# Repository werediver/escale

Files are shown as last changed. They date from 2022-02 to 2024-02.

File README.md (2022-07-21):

# Kitchen / coffee scale

This is a kitchen / coffee scale project repository. Contains both the hardware design files and the firmware source code.

## Prototype one

- [Raspberry Pi Pico](https://www.raspberrypi.com/products/raspberry-pi-pico/)
- Firmware in Rust ([escale_fw_rs](escale_fw_rs/))
- Battery powered (AA×2)

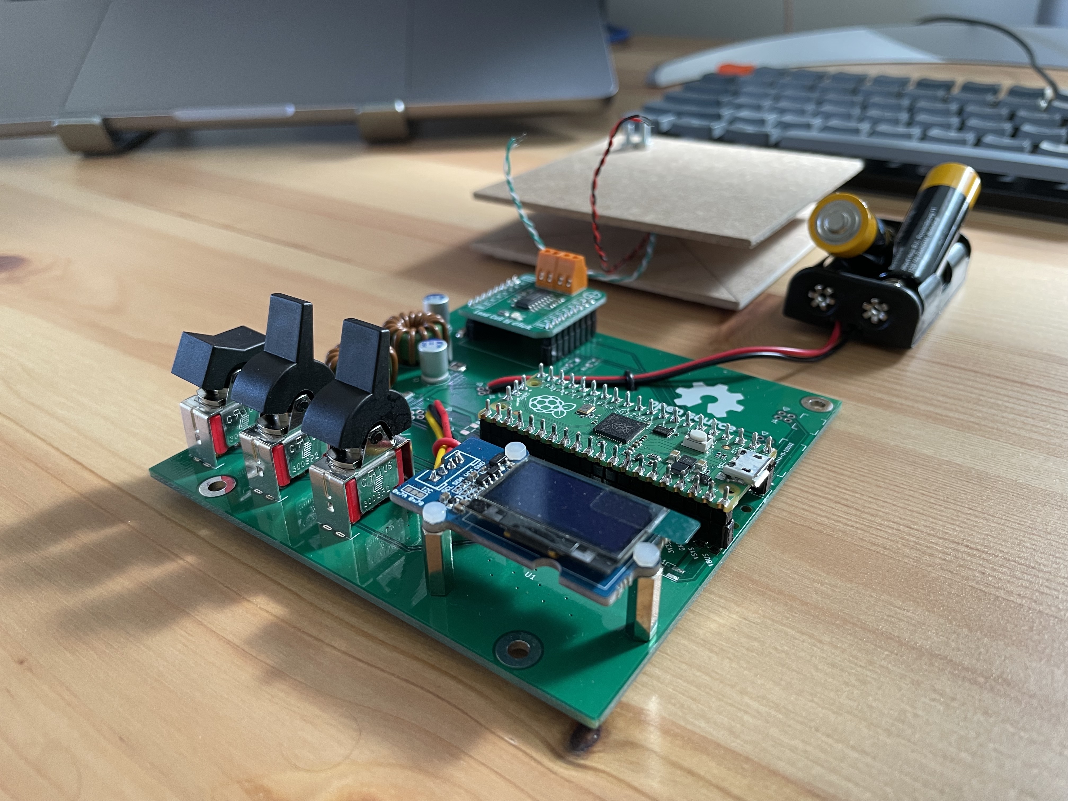
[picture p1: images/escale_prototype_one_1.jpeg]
eScale prototype one


## Prototype zero

The firmware source code is at a very early stage of development. See [escale_fw](escale_fw).

The hardware prototype is assembled on a breadboard and consists of the following components:

- [Seeeduino XIAO](https://wiki.seeedstudio.com/Seeeduino-XIAO/)
- [0.96" SSD1315 OLED display](https://wiki.seeedstudio.com/Grove-OLED-Display-0.96-SSD1315/)
- [MikroE Load Cell 2 Click](https://www.mikroe.com/load-cell-2-click)
- Two 12 mm THT-mount push-buttons

eScale prototype zero with a table

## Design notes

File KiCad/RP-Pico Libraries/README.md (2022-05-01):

# Raspberry Pi Pico KiCad symbols and footprints

Based on [ncarandini/KiCad-RP-Pico](https://github.com/ncarandini/KiCad-RP-Pico/).

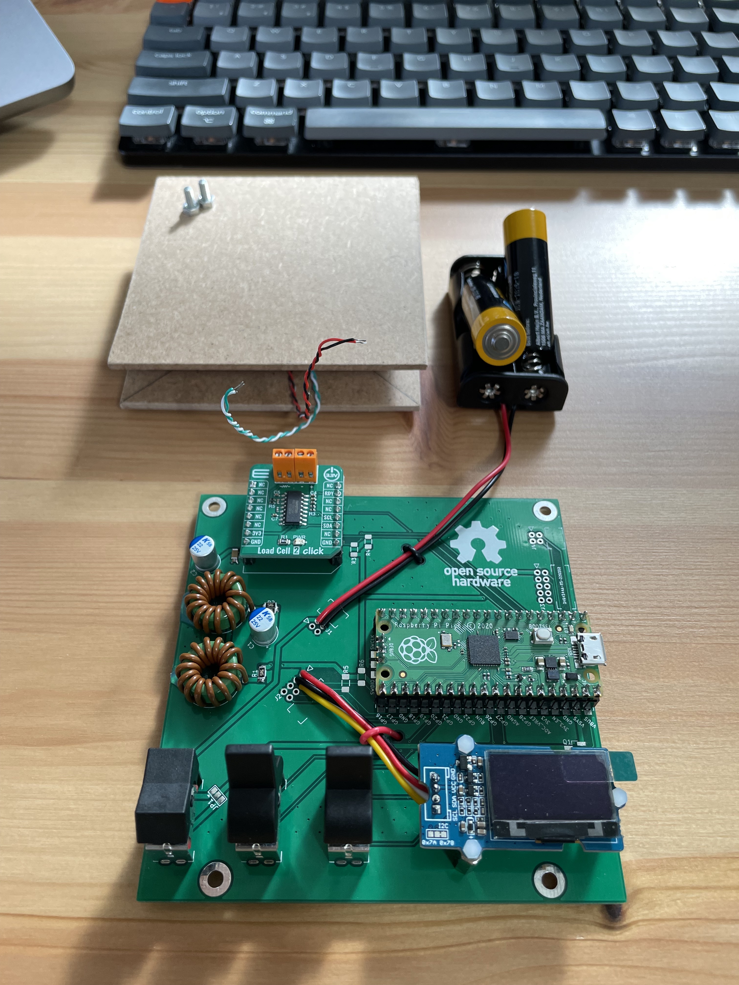
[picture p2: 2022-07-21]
images/escale_prototype_one_2.jpeg

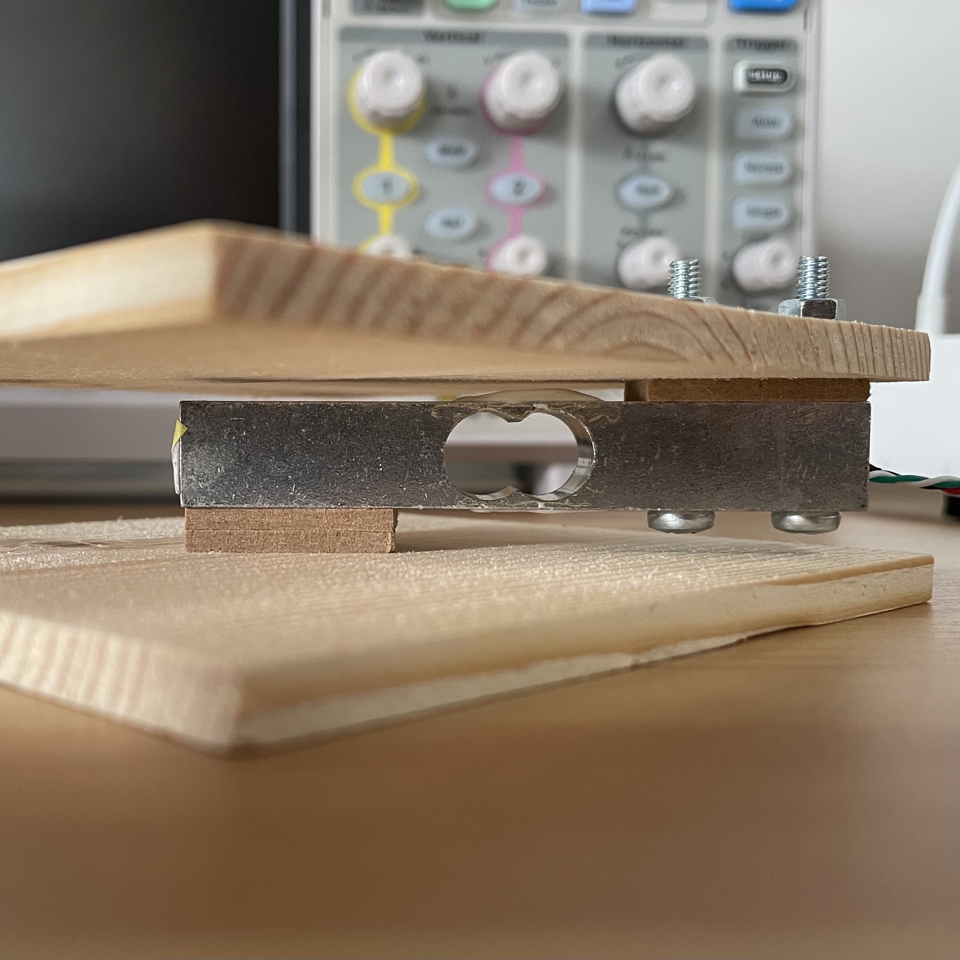
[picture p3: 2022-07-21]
images/escale_prototype_zero_table_close-up.jpg

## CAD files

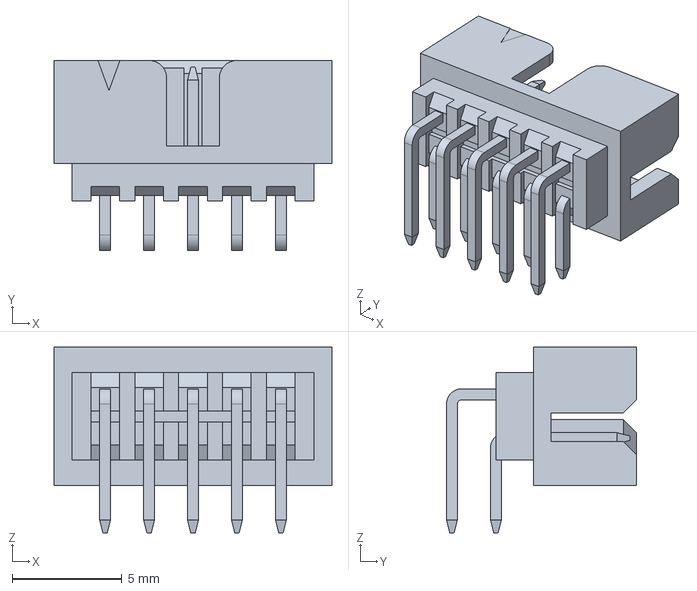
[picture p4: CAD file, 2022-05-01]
KiCad/Molex Milli-Grid/87833-1020.stp
12.7 x 8.65 x 8.46 mm

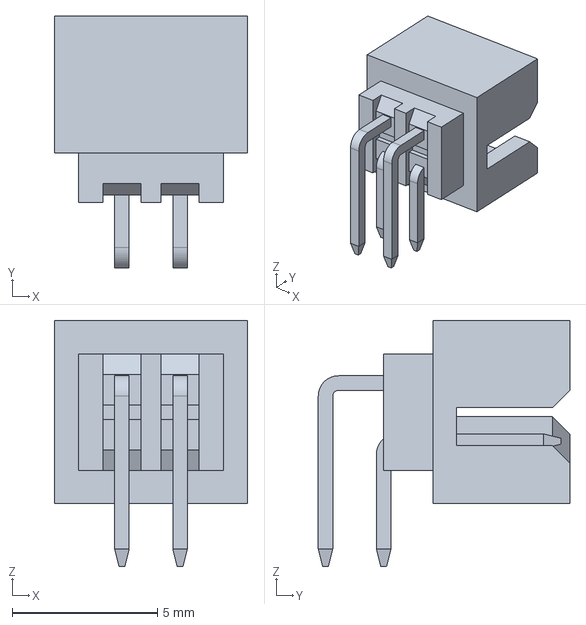
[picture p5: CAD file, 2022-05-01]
KiCad/Molex Milli-Grid/87833-0420.stp
6.65 x 8.65 x 8.46 mm

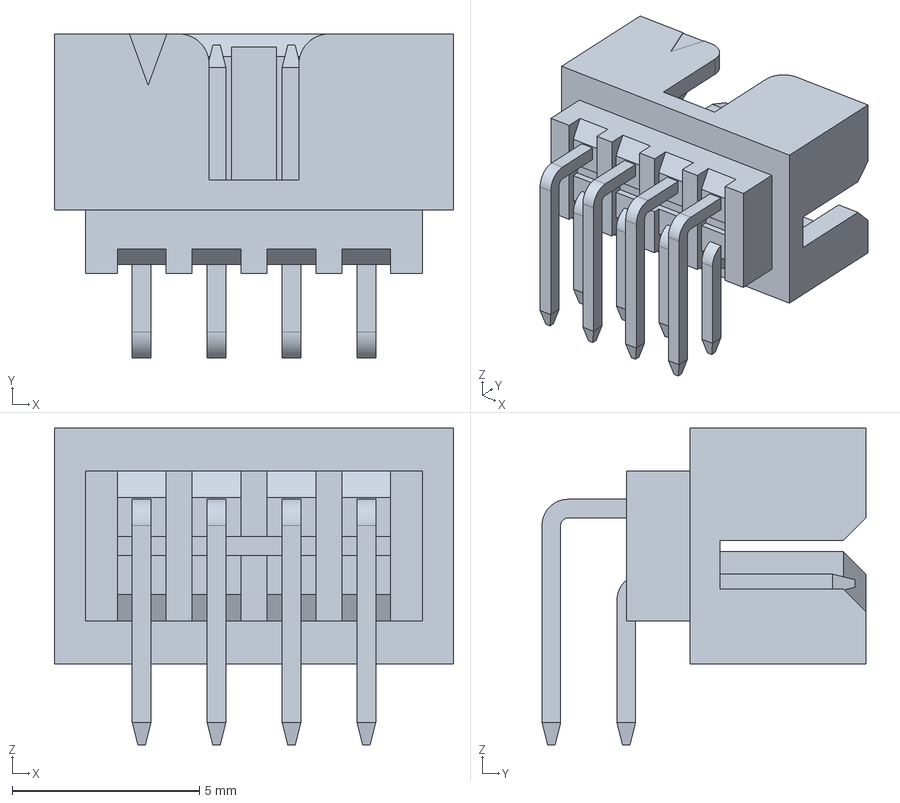
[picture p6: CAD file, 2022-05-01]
KiCad/Molex Milli-Grid/87833-0820.stp
10.7 x 8.65 x 8.46 mm

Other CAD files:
KiCad/Molex Milli-Grid/87833-0420.dxf
KiCad/Molex Milli-Grid/87833-0820.dxf
KiCad/Molex Milli-Grid/87833-1020.dxf

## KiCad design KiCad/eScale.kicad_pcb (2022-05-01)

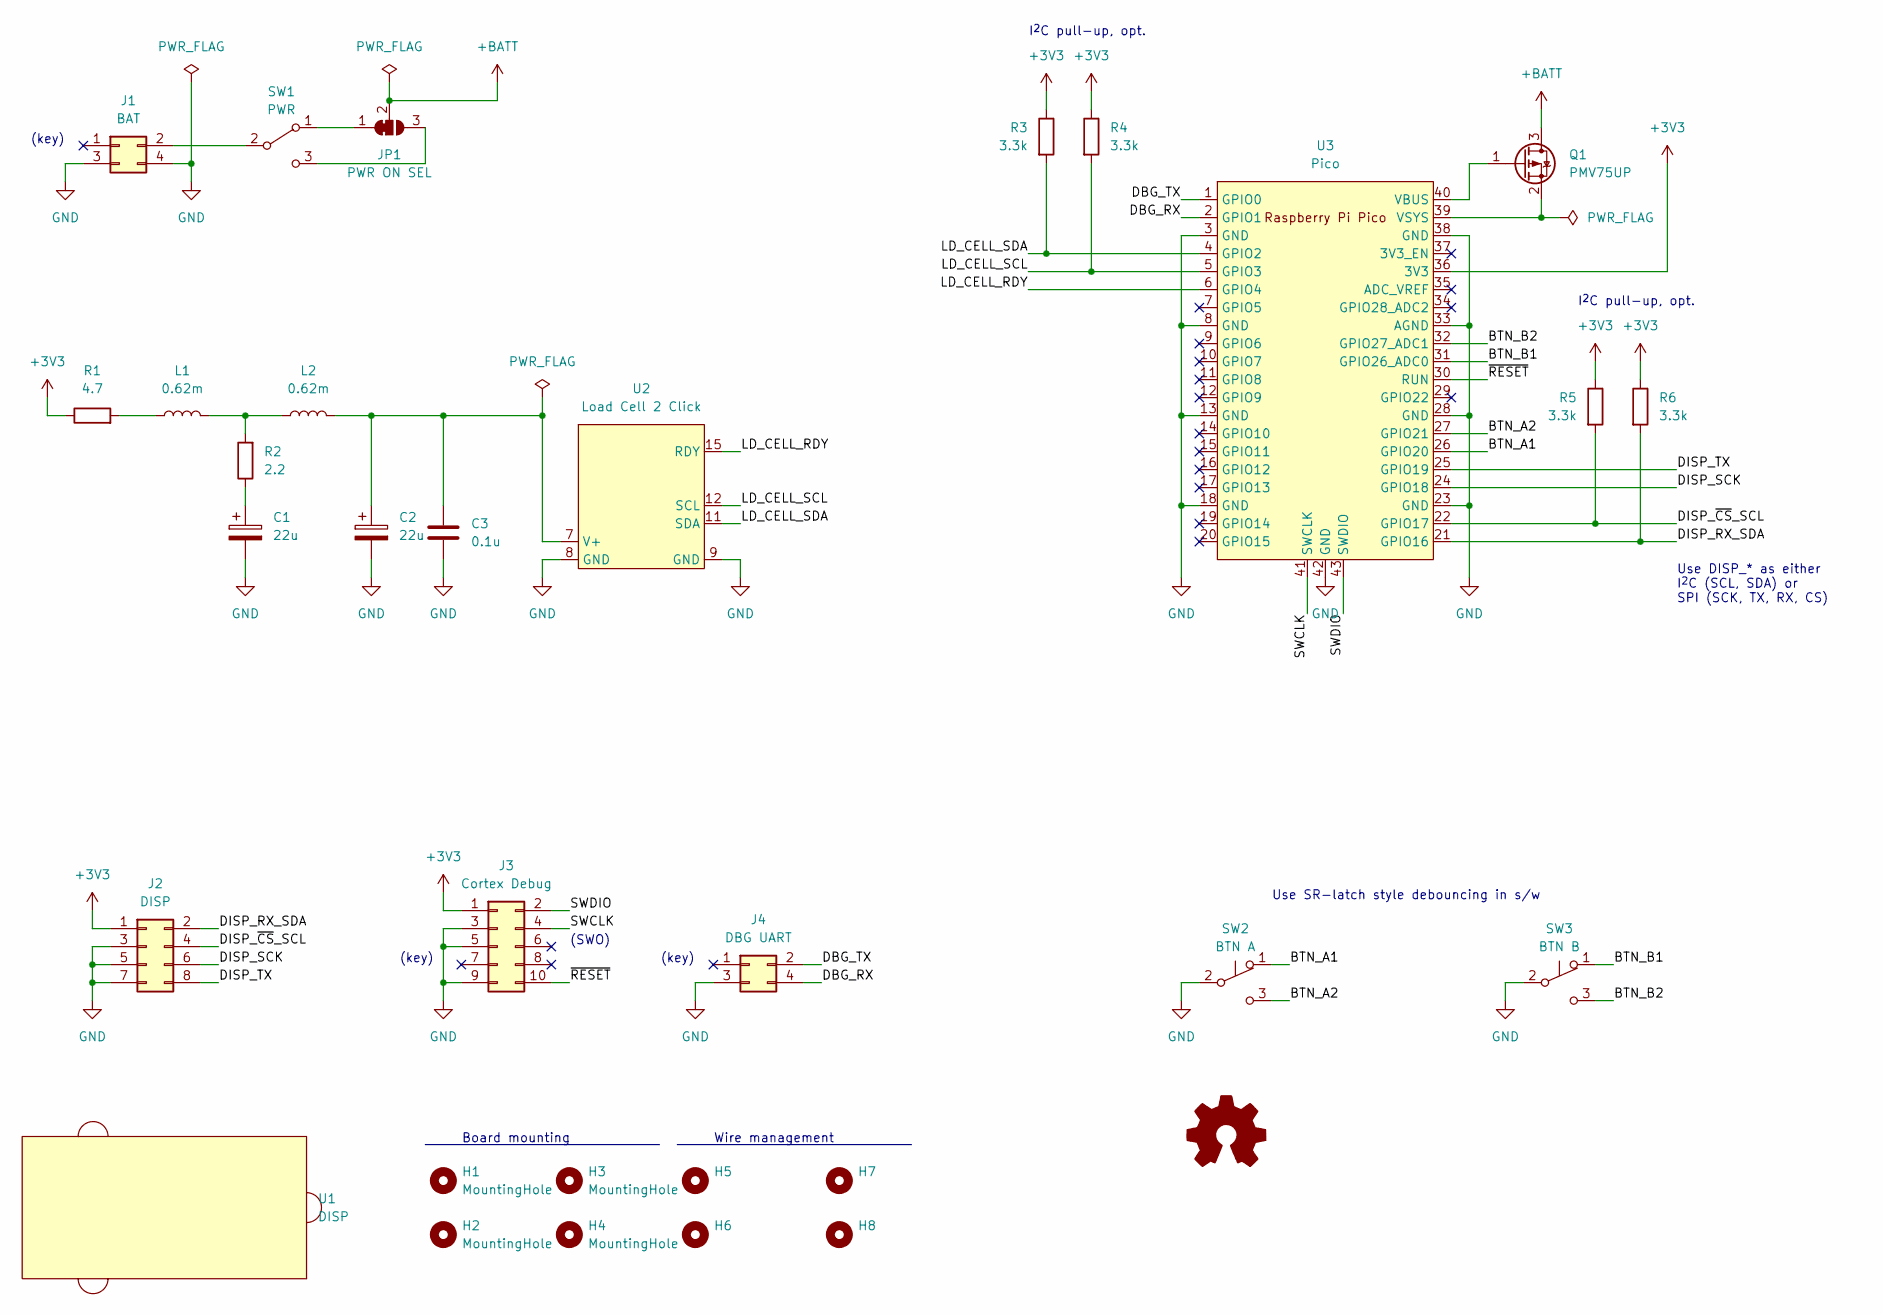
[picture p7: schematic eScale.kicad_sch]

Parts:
C1, C2: 22u; CP_Radial_D6.3mm_P2.50mm
C3: 0.1u; C_1206_3216Metric_Pad1.33x1.80mm_HandSolder
H1, H2, H3, H4: MountingHole; MountingHole_3.2mm_M3_Pad
H5, H6, H7, H8: (no value)
J1: BAT; Molex_Milli-Grid_87833-04xx
J2: DISP; Molex_Milli-Grid_87833-08xx
J3: Cortex Debug; Molex_Milli-Grid_87833-10xx
J4: DBG UART; Molex_Milli-Grid_87833-04xx
JP1: PWR ON SEL; SolderJumper-3_P1.3mm_Bridged12_Pad1.0x1.5mm
L1, L2: 0.62m; L_D13.3_d7.3_Horizontal
LOGO1: (no value)
Q1: PMV75UP; SOT-23_Handsoldering
R1: 4.7; R_1206_3216Metric_Pad1.30x1.75mm_HandSolder
R2: 2.2; R_1206_3216Metric_Pad1.30x1.75mm_HandSolder
R3, R4, R5, R6: 3.3k; R_1206_3216Metric_Pad1.30x1.75mm_HandSolder
SW1: PWR; 300SPxxxxxxVS2xx
SW2: BTN A; 300SPxxxxxxVS2xx
SW3: BTN B; 300SPxxxxxxVS2xx
U1: DISP; Seeed_Grove_20x40
U2: Load Cell 2 Click; MikroE Click
U3: Pico; RPi_Pico_SMD_TH

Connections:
+3V3: J2.1, J3.1, R1.1, R3.1, R4.1, R5.1, R6.1, U3.36 (3V3)
+BATT: JP1.2 (C), Q1.3 (D)
/BTN_A1: SW2.1 (A), U3.26 (GPIO20)
/BTN_A2: SW2.3 (C), U3.27 (GPIO21)
/BTN_B1: SW3.1 (A), U3.31 (GPIO26_ADC0)
/BTN_B2: SW3.3 (C), U3.32 (GPIO27_ADC1)
/DBG_RX: J4.4, U3.2 (GPIO1)
/DBG_TX: J4.2, U3.1 (GPIO0)
/DISP_RX_SDA: J2.2, R6.2, U3.21 (GPIO16)
/DISP_SCK: J2.6, U3.24 (GPIO18)
/DISP_TX: J2.8, U3.25 (GPIO19)
/DISP_~CS_SCL: J2.4, R5.2, U3.22 (GPIO17)
/LD_CELL_RDY: U2.15 (RDY), U3.6 (GPIO4)
/LD_CELL_SCL: R4.2, U2.12 (SCL), U3.5 (GPIO3)
/LD_CELL_SDA: R3.2, U2.11 (SDA), U3.4 (GPIO2)
/SWCLK: J3.4, U3.41 (SWCLK)
/SWDIO: J3.2, U3.43 (SWDIO)
/~RESET: J3.10, U3.30 (RUN)
GND: C1.2, C2.2, C3.2, J1.3, J1.4, J2.3, J2.5, J2.7, J3.3, J3.5, J3.9, J4.3, SW2.2 (B), SW3.2 (B), U2.8 (GND), U2.9 (GND), U3.3 (GND), U3.8 (GND), U3.13 (GND), U3.18 (GND), U3.23 (GND), U3.28 (GND), U3.33 (AGND), U3.38 (GND), U3.42 (GND)
unnamed: C1.1, R2.1
unnamed: C2.1, C3.1, L2.2, U2.7 (V+)
unnamed: J1.2, SW1.2 (B)
unnamed: JP1.1 (A), SW1.1 (A)
unnamed: JP1.3 (B), SW1.3 (C)
unnamed: L1.1, R1.2
unnamed: L1.2, L2.1, R2.2
unnamed: Q1.1 (G), U3.40 (VBUS)
unnamed: Q1.2 (S), U3.39 (VSYS)

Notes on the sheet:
(key)
Board mounting
Use SR-latch style debouncing in s/w
I^{2}C pull-up, opt.
Use DISP_* as either I^{2}C (SCL, SDA) or SPI (SCK, TX, RX, CS)
(SWO)
Wire management

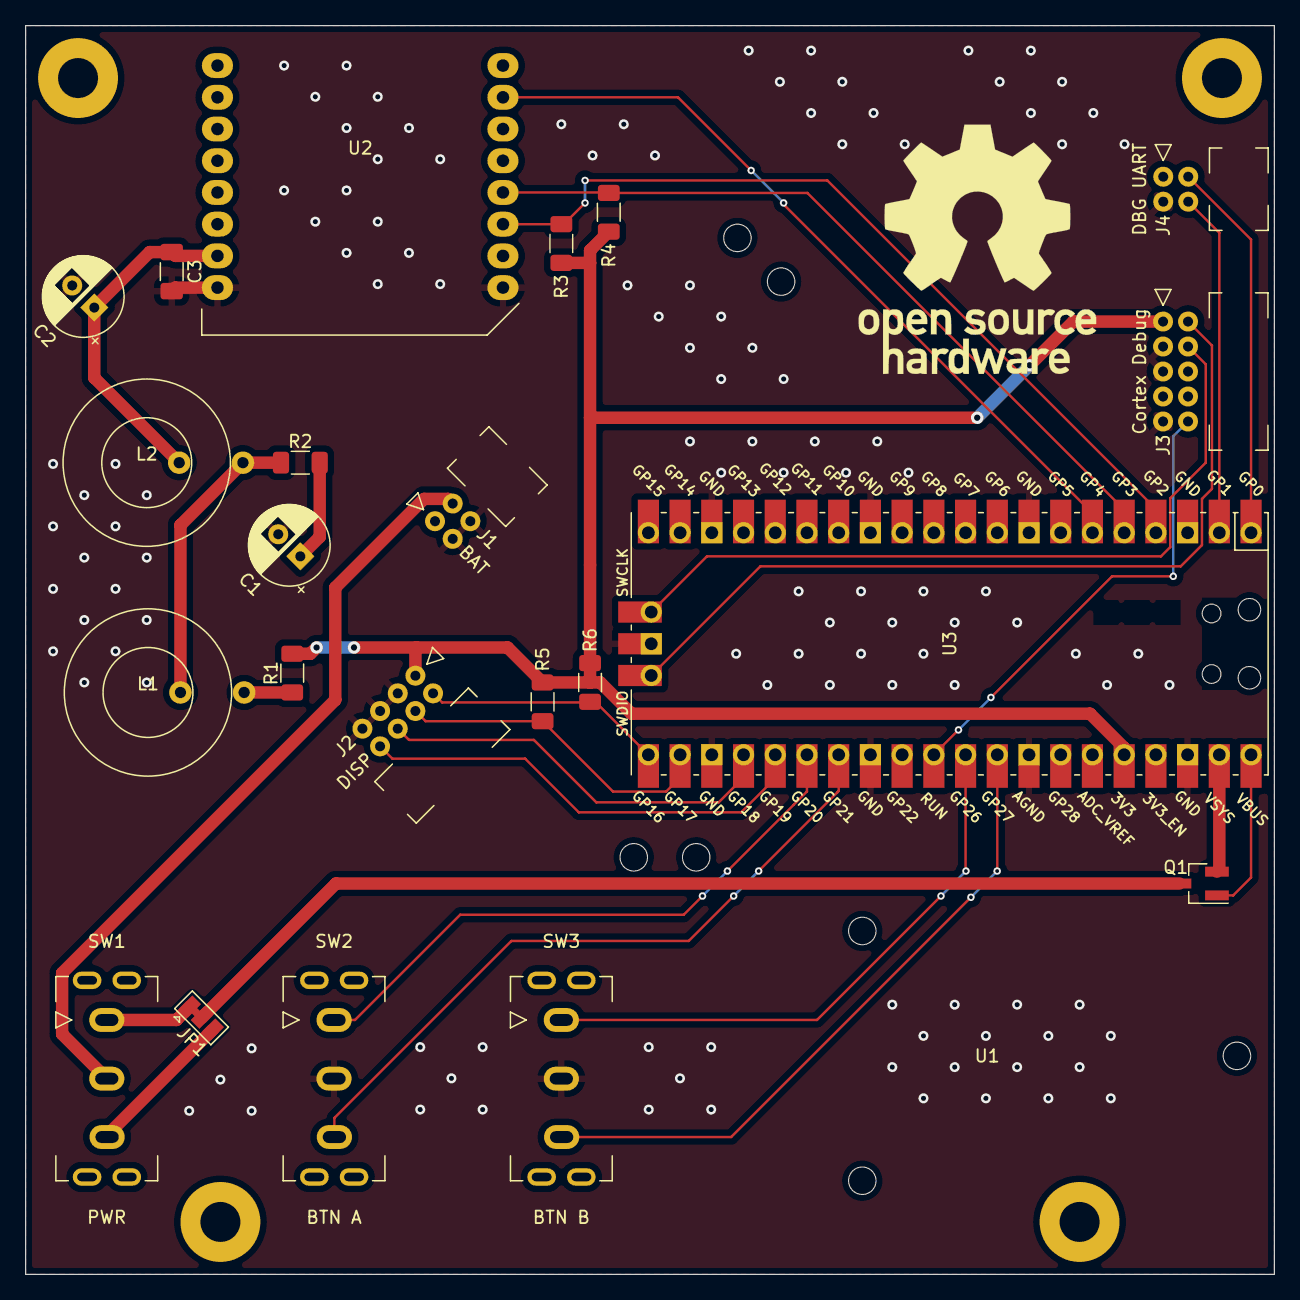
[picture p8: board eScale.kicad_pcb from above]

Board: 2 copper layers, 100.0 x 100.0 mm, 32 parts (0 on the bottom side), 28 nets.

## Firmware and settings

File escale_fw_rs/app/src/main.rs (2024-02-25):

#![no_std]
#![no_main]
#![feature(alloc_error_handler)]
#![feature(trait_alias)]
#![allow(incomplete_features)]
#![feature(generic_const_exprs)]

mod flash;
mod ssd1306_terminal;
mod uptime;
mod uptime_delay;

extern crate alloc;

use alloc::rc::Rc;
use alloc_cortex_m::CortexMHeap;
use core::mem::size_of;
use core::{alloc::Layout, cell::RefCell};
use embedded_hal::digital::v2::InputPin;
use flash::{Flash, FLASH_ORIGIN};
use fugit::RateExtU32;
use panic_probe as _;

use rp_pico as bsp;

use bsp::hal;
use bsp::hal::{clocks::init_clocks_and_plls, pac, sio::Sio, Clock, Watchdog, I2C};

use nau7802::{Gain, Ldo, Nau7802, SamplesPerSecond};
use ssd1306::{
    mode::DisplayConfig, rotation::DisplayRotation, size::DisplaySize128x64, I2CDisplayInterface,
    Ssd1306,
};

use app_core::{
    common::{AppContext, AppMessage, AppTask},
    dashboard::Dashboard,
    input_scanner::InputScanner,
    scale::Scale,
    terminal::Terminal,
};
use ssd1306_terminal::Ssd1306Terminal;
use stuff::{
    mq::MessageProcessingStatus,
    run_loop::{FnTask, Schedule, Task, TaskStatus},
};
use uptime::Uptime;

#[alloc_error_handler]
fn oom(_: Layout) -> ! {
    loop {
        cortex_m::asm::wfi();
    }
}

#[global_allocator]
static ALLOCATOR: CortexMHeap = CortexMHeap::empty();

#[allow(non_upper_case_globals)]
const MiB: usize = 1024 * 1024;
const FLASH_END: usize = FLASH_ORIGIN + 2 * MiB;
const FLASH_CONF_ADDR: usize = FLASH_END - size_of::<Flash<Conf>>();

#[repr(C)]
#[derive(Copy, Clone)]
struct Conf {
    format: u16,
    scale_unit: f32,
}

impl Default for Conf {
    fn default() -> Self {
        Self {
            format: 1,
            scale_unit: 1.0,
        }
    }
}

impl Conf {
    fn is_valid(&self) -> bool {
        self.format != 0 && !self.format != 0
    }
}

fn init_heap() {
    use core::mem::MaybeUninit;
    const HEAP_SIZE: usize = 128 * 1024;
    static mut HEAP: [MaybeUninit<u8>; HEAP_SIZE] = [MaybeUninit::uninit(); HEAP_SIZE];
    unsafe { ALLOCATOR.init(HEAP.as_ptr() as usize, HEAP_SIZE) }
}

#[hal::entry]
fn _main() -> ! {
    init_heap();

    let mut pac = pac::Peripherals::take().unwrap();
    let sio = Sio::new(pac.SIO);

    let core = pac::CorePeripherals::take().unwrap();
    let mut uptime = Uptime::new(core.SYST);

    let pins = bsp::Pins::new(
        pac.IO_BANK0,
        pac.PADS_BANK0,
        sio.gpio_bank0,
        &mut pac.RESETS,
    );

    let mut watchdog = Watchdog::new(pac.WATCHDOG);

    // External high-speed crystal on the pico board is 12Mhz
    let external_xtal_freq_hz = 12_000_000u32;
    let clocks = init_clocks_and_plls(
        external_xtal_freq_hz,
        pac.XOSC,
        pac.CLOCKS,
        pac.PLL_SYS,
        pac.PLL_USB,
        &mut pac.RESETS,
        &mut watchdog,
    )
    .ok()
    .unwrap();

    let i2c0 = I2C::i2c0(
        pac.I2C0,
        pins.gpio16.into_function(),
        pins.gpio17.into_function(),
        400.kHz(),
        &mut pac.RESETS,
        clocks.system_clock.freq(),
    );

    let mut cx = AppContext::default();
    let mut schedule: Schedule<AppTask, AppContext> = Schedule::default();

    let button_a_pin = pins.gpio20.into_pull_up_input();
    let button_b_pin = pins.gpio26.into_pull_up_input();

    schedule.push(AppTask::InputScanner(InputScanner::new(
        move || button_a_pin.is_low().unwrap(),
        move || button_b_pin.is_low().unwrap(),
        Uptime::get_instant,
    )));

    let interface = I2CDisplayInterface::new(i2c0);
    let mut ssd1306 =
        Ssd1306::new(interface, DisplaySize128x64, DisplayRotation::Rotate0).into_terminal_mode();
    ssd1306.init().unwrap();
    let shared_terminal = Rc::new(RefCell::new(Ssd1306Terminal::new(ssd1306)));
    {
        let mut terminal = shared_terminal.borrow_mut();
        terminal.clear().unwrap();
    }
    schedule.push(AppTask::Dashboard(Dashboard::new(
        shared_terminal,
        Uptime::get_instant,
    )));

    let conf = {
        let conf: Conf = unsafe { Flash::read(FLASH_CONF_ADDR).value().assume_init() };

        if conf.is_valid() {
            conf
        } else {
            Default::default()
        }
    };

    let i2c1 = I2C::i2c1(
        pac.I2C1,
        pins.gpio2.into_function(),
        pins.gpio3.into_function(),
        400.kHz(),
        &mut pac.RESETS,
        clocks.system_clock.freq(),
    );
    let mut nau7802 = Nau7802::new_with_settings(
        i2c1,
        Ldo::L3v0,
        Gain::G128,
        SamplesPerSecond::SPS20,
        &mut uptime,
    )
    .unwrap();
    let mut scale = Scale::<i32, f32, 20>::default();
    scale.set_unit(conf.scale_unit);

    schedule.push(AppTask::Fn(FnTask::new(move |cx: &mut AppContext| {
        if nau7802.data_available().unwrap() {
            let raw = nau7802.read_unchecked().unwrap();
            scale.push(raw);
            if scale.is_filled() {
                cx.mq.process(|m, _push| match m {
                    AppMessage::Tare => {
                        scale.capture_tare().unwrap();
                        MessageProcessingStatus::Processed
                    }
                    AppMessage::Calibrate => {
                        scale.capture_unit(100.0).unwrap();
                        let conf = Conf {
                            scale_unit: scale.get_unit(),
                            ..Default::default()
                        };
                        cortex_m::interrupt::free(|_cs| unsafe {
                            Flash::new(conf).write(FLASH_CONF_ADDR)
                        });
                        MessageProcessingStatus::Processed
                    }
                    _ => MessageProcessingStatus::Ignored,
                });
                cx.state.weight = scale.read().unwrap();
            }
        }
        TaskStatus::Pending
    })));

    cx.mq.push(AppMessage::Tare);

    loop {
        schedule.run(&mut cx);
    }
}

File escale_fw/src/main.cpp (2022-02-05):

#include "app_hal/button.hpp"
#include "app_hal/display/u8g2display.hpp"
#include "app_state.hpp"
#include "run_loop/run_loop.hpp"
#include "ui/calibration/calibration_task.hpp"
#include "ui/calibration/calibration_view.hpp"
#include "ui/dashboard/dashboard_task.hpp"
#include "ui/dashboard/dashboard_view.hpp"
#include "ui/message/message_view.hpp"
#include "ui/taring/taring_task.hpp"
#include "ui/view_stack_task.hpp"

#include "filtering/median_filter.hpp"
#include "filtering/fir_filter.hpp"
#include "filtering/threshold_change_detector.hpp"

#include <Arduino.h>
#include <SparkFun_Qwiic_Scale_NAU7802_Arduino_Library.h>
#include <U8g2lib.h>

U8G2_SSD1306_128X64_NONAME_F_HW_I2C u8g2{U8G2_R0, U8X8_PIN_NONE, SCL, SDA};
AppHAL::U8G2Display display{u8g2};
NAU7802 nau7802;

const uint32_t buttonAPin = 7;
const uint32_t buttonBPin = 8;
const unsigned long buttonToggleHoldOffDuration = 20; // ms
AppHAL::Button buttonA{buttonToggleHoldOffDuration};
AppHAL::Button buttonB{buttonToggleHoldOffDuration};

AppState state;
RunLoop::RunLoop<AppState> runLoop;

void readButtons(RunLoop::RunLoop<AppState> &runLoop)
{
  if (const auto pViewStack = runLoop.find<UI::ViewStackTask<AppState>>())
  {
    if (const auto pInputHandler = pViewStack->back())
    {
      if (buttonA.clearIsDownPending())
        pInputHandler->handleInputEvent(
            {UI::ButtonEvent::ButtonTag::A,
             UI::ButtonEvent::Type::ButtonDown});
      if (buttonB.clearIsDownPending())
        pInputHandler->handleInputEvent(
            {UI::ButtonEvent::ButtonTag::B,
             UI::ButtonEvent::Type::ButtonDown});
    }
  }
}

filtering::MedianFilter<std::int32_t> rawWeightFilter1{5};
filtering::FIRFilter rawWeightFilter2;
filtering::ThresholdChangeDetector<filtering::Real> weightChangeDetector(
    2.0f,
    []()
    {
      rawWeightFilter1.reset();
      rawWeightFilter2.reset();
    });

void readWeight(AppState &state)
{
  auto rawToWeight = [&](std::int32_t rawWeight)
  { return (rawWeight - state.zeroOffset) / state.calibrationFactor; };

  for (auto i = 0; i < 64; ++i)
  {
    const auto newRawWeigh = rawWeightFilter1.apply(nau7802.getAverage(1));
    weightChangeDetector.apply(rawToWeight(newRawWeigh));
    state.rawWeigh = rawWeightFilter2.apply(newRawWeigh);
    state.weight = rawToWeight(state.rawWeigh);
    state.readCount += 1;
  }
}

static constexpr auto refSampleCount = 320 * 3;

void calculateZeroOffset(AppState &state)
{
  rawWeightFilter1.reset();
  rawWeightFilter2.reset();

  std::int64_t rawWeight = 0;
  auto n = 0;
  for (const auto endReadCount = state.readCount + refSampleCount; state.readCount < endReadCount;)
  {
    readWeight(state);
    rawWeight += state.rawWeigh;
    n += 1;
  }
  rawWeight /= n;
  state.zeroOffset = (std::int32_t)rawWeight;
}

void calculateCalibrationFactor(AppState &state)
{
  static constexpr auto refWeight = 100;
  std::int64_t rawWeight = 0;
  auto n = 0;
  for (const auto endReadCount = state.readCount + refSampleCount; state.readCount < endReadCount;)
  {
    readWeight(state);
    rawWeight += state.rawWeigh;
    n += 1;
  }
  rawWeight /= n;
  state.calibrationFactor = ((std::int32_t)rawWeight - state.zeroOffset) / refWeight;
}

void updateButtons()
{
  const unsigned long now = millis();
  buttonA.update(
      digitalRead(buttonAPin) == 0
          ? AppHAL::Button::State::Down
          : AppHAL::Button::State::Up,
      now);
  buttonB.update(
      digitalRead(buttonBPin) == 0
          ? AppHAL::Button::State::Down
          : AppHAL::Button::State::Up,
      now);
}

void setup()
{
  pinMode(buttonAPin, INPUT_PULLUP);
  pinMode(buttonBPin, INPUT_PULLUP);

  attachInterrupt(buttonAPin, updateButtons, CHANGE);
  attachInterrupt(buttonBPin, updateButtons, CHANGE);

  u8g2.begin();
  u8g2.setFont(u8g2_font_profont12_tf);

  if (nau7802.begin())
  {
    nau7802.setGain(NAU7802_GAIN_128);
    nau7802.setSampleRate(NAU7802_SPS_320);
    nau7802.calibrateAFE();

    const auto rawWeightSample = nau7802.getAverage(1);
    calculateZeroOffset(state);

    state.rawWeigh = rawWeightSample;
  }

  runLoop.push_back(std::make_shared<RunLoop::FuncTask<AppState>>(
      [](RunLoop::RunLoop<AppState> &runLoop, AppState &state)
      {
        readButtons(runLoop);
        readWeight(state);
      }));
  runLoop.push_back(std::make_shared<UI::ViewStackTask<AppState>>(display));
  runLoop.push_back(std::make_shared<UI::DashboardTask<AppState>>(
      []()
      { return std::make_shared<UI::TaringTask<AppState>>(
            []()
            { calculateZeroOffset(state); }); },
      []()
      { return std::make_shared<UI::CalibrationTask<AppState>>(
            []()
            { calculateCalibrationFactor(state); },
            [](const AppState &state)
            {
              return UI::CalibrationViewModel{state.zeroOffset, state.rawWeigh};
            }); },
      [](const AppState &state)
      { return UI::DashboardViewModel{state.weight}; }));
}

void loop()
{
  runLoop.run(state);
}

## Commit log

2021-06-12 Implement interrupt-driven button interface with debouncing
2021-07-03 Rework `AppHAL::InputHandler`, introduce `AppInput::ButtonEvent`
    [main.cpp]
2021-07-05 Rework `UI::SomeView` to allow implementing views through subclassing
    [main.cpp]
2021-07-12 Introduce `DashboardTask`, rework header guards, use `= default` destructors in interfaces, clean up
    [main.cpp]
2021-07-17 Fix `readButtons` (reading from an empty vector), introduce "debug" module
    [main.cpp]
2021-07-24 Update weight averaging four samples
2021-08-07 Some Octave code to design FIR filters
2022-02-05 Latest (WIP) changes with taring, calibration, and some filtering
2022-05-01 Add the KiCad files for a Raspberry Pi Pico based board
    [87833-0420.dxf, 87833-0420.stp, 87833-0820.dxf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]
2022-07-17 Introduce `Button` helper (in "input_scanner.rs)
2022-07-21 Implement a stopwatch (based on SysTick timer)
2022-08-01 Introduce `Ring.is_filled()` and `Ring.reset()`
    [main.rs]
2022-09-27 Persist the calibration parameter
2022-09-27 Replace the use of "flash_static.rs" with a new implementation (not relying on static vars anymore)
    [main.rs]
